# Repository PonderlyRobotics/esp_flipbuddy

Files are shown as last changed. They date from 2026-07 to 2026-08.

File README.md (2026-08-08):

# FlipBuddy







I kept forgetting to start and stop phone time trackers. FlipBuddy is my fix: a printed cube on the desk. Face up means that activity is on (not a countdown alarm). Flip when you switch; stop face when you are done. The cube logs face changes. LEDs show the colors you set in the free app at [flipbuddy.app](https://flipbuddy.app) if you use it.

I thought it would take a weekend. It took months. That is fine. Still a simple cube: flip a face, log the time, check history later in the free app if you want.

Hackaday wrote about the project:  
https://hackaday.com/2026/08/07/flipbuddy-is-borg-you-will-be-assimilated/

This repository is the open DIY build. Firmware is **0.1.4**. It runs on a stock ESP32-S3 (Super Mini class works well) with MicroPython. The shell STLs and assembly PDF are here too. I publish it under **Ponderly Robotics** and work on it when evenings allow, so please treat it as a hobby project, not a product with phone support.

<p align="center">
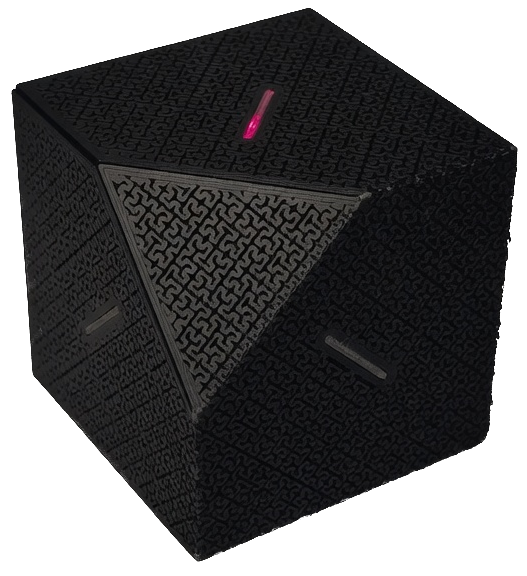
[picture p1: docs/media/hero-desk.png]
FlipBuddy cube with activity LED lit
  
</p>

If you only want to build one, start with the [assembly PDF](./FlipBuddy%20Assembly%20guide.pdf), the files in [stl/](./stl/), the firmware `.bin` from GitHub Releases, then `main.py` and your `credentials.json`. You can ignore `scripts/`, pre-commit, and the rest of the host tooling. People changing the code should read [CONTRIBUTING.md](./CONTRIBUTING.md).

| | |
|--|--|
| Firmware image | `esp32_s3_flipbuddy_0.1.4.bin` on GitHub Releases (MicroPython 1.27; helpers frozen in; not in git) |
| Enclosure | [stl/](./stl/) |
| Assembly | [FlipBuddy Assembly guide.pdf](./FlipBuddy%20Assembly%20guide.pdf) |
| Software license | [MIT](./LICENSE) |
| Hardware license | [CC BY-NC-SA 4.0](./LICENSE-HARDWARE) |

The design is for minutes and hours, not a stopwatch. It prefers boards you can buy today. Other custom modules are not in this tree yet.

## Contents

- [Features in short](#features-in-short)
- [Day to day](#day-to-day)
- [SoftAP maintenance mode](#softap-maintenance-mode)
- [Battery (rough)](#battery-rough)
- [Getting started](#getting-started)
  - [Serial port and board](#serial-port-and-board-justfile)
  - [Fast track (v0.1.4)](#fast-track-v013)
  - [DIY path](#diy-path)
- [Assembly, printing, and parts](#assembly-printing-and-parts)
- [Web app](#web-app)
- [FAQ](#faq)
- [Bugs](#bugs)
- [Contributing](#contributing)
- [License](#license)
- [Links](#links)

## Features in short

- Up to 8 faces (one can be stop)
- Snap-fit printed shell
- RGB LEDs for activity colors from the app
- Deep sleep and longer sleeps on the stop face
- Free web app for names, colors, history, optional AI
- More than one cube per account (stop one in the app before using another a lot)

## Day to day

You set activity names, descriptions, and colors in the browser, plus device settings (for example OTA on/off, how often the cube wakes, and how often it should join Wi-Fi and check in with the server). The cube records which face is up and when (activity periods).

When the cube is online it talks both ways with the free app:
- **Up:** upload face changes (activity periods) for history on flipbuddy.app
- **Down:** pull activity name, description, color, and device configuration for that cube

Wi-Fi is used for those check-ins, sometimes on the stop face, and when USB is plugged in. On stop, sleep intervals grow so the battery lasts longer.

If Wi-Fi is down but credentials are already installed, the cube still boots and can log with defaults (last known face map). Full face colors, fresh names, and history still need flipbuddy.app for normal use.

USB-C face up can open **SoftAP maintenance mode** (local captive portal — see below). Blinking all leds red often means bad orientation or low battery. AI in the app can be turned off.

## SoftAP maintenance mode

When the **USB‑C face** is up (the face with the USB‑C **port**; SoftAP is **on by default** in firmware, advanced builds can disable it), the cube soft‑resets into a short **SoftAP** session so you can check status and fix Wi‑Fi **without** `mpremote`.

Full SoftAP needs the portal modules on the device: the **0.1.4** frozen Release image (or later), **or** DIY/`just diy` (full source upload). Fast track only pushes `main.py` + credentials on top of the frozen set. Risks (open AP, cleartext HTTP, PIN): [SECURITY.md](./SECURITY.md).

| | |
|--|--|
| Join Wi‑Fi | Open network **`FlipBuddy`** (no AP password) |
| Portal URL | [http://10.20.30.40/](http://10.20.30.40/) (captive portal usually opens this) |
| Session length | About **5 minutes**, then SoftAP stops and the cube deep‑sleeps |
| Transport | **HTTP only** (cleartext) |

### Builder steps

1. Put the **USB‑C port face** up. Wait until the phone sees open Wi‑Fi **`FlipBuddy`** (shake to wake if the cube slept).
2. Join **`FlipBuddy`**. If no captive browser popup, open **http://10.20.30.40/**.
3. Unlock with the **setup PIN** (below) if you need to change Wi‑Fi or PIN.
4. Save home SSID/password if needed. Keep **only one phone** on `FlipBuddy` while settings are unlocked ([why](./SECURITY.md#softap-captive-portal-http-pin-wi-fi)).
5. **Exit:**
   - Tap **Reset device** on the portal (preferred after clock issues), **or** wait for SoftAP to end (~5 min).
   - Flip to a **non‑cutout** face (activity or stop — not either shell cutout).
   - On the phone, leave `FlipBuddy` and rejoin your **home** Wi‑Fi.
6. SoftAP again later: **leave the USB face first** (cooldown after a session), then put USB face up again.

**Timeout vs Reset:** SoftAP timeout turns SoftAP off, deepsleeps briefly, then normal wake (may use home Wi‑Fi / NTP if already configured). **Reset device** (or power‑cycle) runs a full boot with forced Wi‑Fi + NTP — use that when the clock is wrong.

### Default unlock PIN

Settings that **write** to the cube need a **setup PIN** unlock for that SoftAP session:

- **Factory default:** last **6** alphanumeric characters of your **`device_id`**, uppercased (ignore hyphens/punctuation).  
  Example: `device_id` ending in `…ABCDEF123456` → default PIN **`123456`**.
- **Custom PIN:** after unlock, set 4–16 letters/numbers on the portal (stored in NVS); then the factory rule no longer applies.
- Wrong PIN is rate‑limited (**8** tries); then unlock locks until reboot. Portal **Reset device** still works and reboots the cube.
- Unlock idles out after about 5 minutes of no settings use — use **Lock settings** when finished.

You can find `device_id` in the downloaded `credentials.json` or in the flipbuddy.app device page. The cube does not display the PIN.

### What the captive portal shows

**Always available (no PIN):**

- Device **UTC time** and **battery** (percent / voltage; USB‑aware) on the top bar
- Face map / activity colors as stored on the cube
- Local activity records not yet uploaded (when any)
- **Reset device** (not PIN‑protected — physical USB‑face access is assumed)

**After PIN unlock:**

- Add or update **Wi‑Fi** profiles (SSID, password, hidden flag) in NVS
- **Change unlock PIN**
- **LED self‑test**
- **Lock** the settings section again

`device_token` is never shown or edited on SoftAP. To replace API credentials, re‑upload `credentials.json` over USB (`just put-credentials` / `just fast-track`).

### Which face is which?

If you have looked at photos or printed one already, you may think: this thing is symmetric, so which side is front, left, or “programming”?

I could have put a different emblem, number, texture, or color on each face. I actually tried. My OCD did not approve of any of them.

So it works like this: when you grab, move, or tap the cube, the accelerometer wakes it and every face that has an activity lights up in that activity’s color. The lights stay on for a few seconds (about 5–7) and dim so you can see the map. I do not need to know if “Human Programming” is assigned to left or bottom. I only need it flashing green and pointing up. Orange is “AI shenanigans” for me. Whichever physical face that is does not matter. Color on top is enough.

## Battery (rough)

With a ~550 mAh LiPo, order-of-magnitude only:

| Scenario | Avg current | Est. life |
|---|---|---|
| Continuous tracking | ~7.4 mA | ~3 days |
| Long stop-face (backoff ~15 min) | ~0.8 mA | ~28 days |
| Mixed use (~10 h tracking/day) | ~3.5 mA | ~6.5 days |

See comments in `main.py` (`prepare_for_deep_sleep`) and `fsm.dot` for the assumptions.

## Getting started

Build and wire the cube first ([assembly section](#assembly-printing--bom) and the [PDF](./FlipBuddy%20Assembly%20guide.pdf)). Pins live in `main.py` / `mpu6050.py`.

| Path | Use when | What you put on the device |
|---|---|---|
| [Fast track](#fast-track-v013) | ESP32-S3 Super Mini (or similar) with charger | Release `.bin`, then `main.py` + `credentials.json` |
| [DIY path](#diy-path) | Other boards, or you want every `.py` on the filesystem | Stock MicroPython + all sources + credentials |

### Serial port and board (`justfile`)

Defaults target an ESP32-S3 Super Mini (4 MB flash) on Linux. Edit the top of [justfile](./justfile) or set `AMPY_PORT`:

```just
usb_dev := env("AMPY_PORT", "/dev/ttyACM0")
esp_chip := "s3"
esp_flash_size := "4MB"
```

| Setting | Default | Notes |
|---|---|---|
| `usb_dev` / `AMPY_PORT` | `/dev/ttyACM0` | Also try `/dev/ttyUSB0`, `COM3`, `/dev/cu.usbmodem*` |
| `esp_chip` | `s3` | Becomes `esp32s3` for esptool |
| `esp_flash_size` | `4MB` | Match your module when picking MicroPython builds |

```bash
just env
```

The Release fast-track image is ESP32-S3 only. Other chips need the DIY path. Commands below use `/dev/ttyACM0` and `esp32s3`; change them if you are not using `just`.

### Fast track (v0.1.4)

Helpers (including SoftAP portal modules) are frozen into the image. You only place `main.py` and `credentials.json` on the filesystem so you can tweak the entrypoint without rebuilding MicroPython.

| | |
|--|--|
| Image | `esp32_s3_flipbuddy_0.1.4.bin` from GitHub **Releases** |
| Checksum | Matching `.bin.sha256` or `SHA256SUMS` on the same release |
| Runtime | MicroPython 1.27 |
| Board | ESP32-S3 Super Mini class with battery charger |

#### 1. Download, verify, flash

Use this README for flashing. The assembly PDF is for mechanics; if it only mentions stock MicroPython, prefer the frozen Release image for Super Mini.

On GitHub: **Releases** → tag **v0.1.4** (or latest 0.1.x). Download the `.bin` and checksum file.

```bash
sha256sum -c esp32_s3_flipbuddy_0.1.4.bin.sha256

esptool --chip esp32s3 --port /dev/ttyACM0 erase-flash
esptool --chip esp32s3 --port /dev/ttyACM0 --baud 460800 write-flash 0 esp32_s3_flipbuddy_0.1.4.bin
```

Or, with the file in the repo directory:

```bash
just flash-firmware esp32_s3_flipbuddy_0.1.4.bin
```

#### 2. Credentials

1. Create a free account at [flipbuddy.app](https://flipbuddy.app)
2. Register a device and download `credentials.json`
3. Add your Wi-Fi (people often skip this):

```json
{
  "device_id": "...",
  "device_token": "...",
  "api_url": "https://api.flipbuddy.app/v1/api/",
  "wifi": {
    "home": { "ssid": "YourWiFi", "password": "secret" }
  }
}
```

The firmware scans for visible SSIDs before connecting. For a hidden network, set `"hidden": true` on that entry.

#### 3. Upload `main.py` and credentials

Put `credentials.json` next to the `justfile`, then:

```bash
just fast-track
# same as: just put-main && just put-credentials
```

That only pushes **`main.py`** and **`credentials.json`**. Do not run `just diy` / `just upload` on the fast track unless you mean to override frozen modules.

Manual equivalent (if you do not use `just`):

```bash
mpremote connect /dev/ttyACM0 cp main.py :
mpremote connect /dev/ttyACM0 cp credentials.json :
```

#### 4. Power cycle

On first boot it will try Wi-Fi, calibrate, fetch face config, then track flips. LEDs should match dashboard colors. Use `just shell` or any 115200 serial console if something looks wrong. Shake the cube if it went to sleep.

### DIY path

For other boards, stock MicroPython, or editing modules on the filesystem.

Get a MicroPython build for your chip and flash size from [micropython.org](https://micropython.org/download/) (1.27+ is a good match). Adjust `justfile` chip/port/flash size as needed.

```bash
esptool --chip esp32s3 --port /dev/ttyACM0 erase-flash
esptool --chip esp32s3 --port /dev/ttyACM0 --baud 460800 write-flash 0 ESP32_GENERIC_S3-....bin
# or: just flash-firmware ESP32_GENERIC_S3-....bin
```

Credentials: same as fast track step 2 (`credentials.json` next to the `justfile`).

```bash
just diy
# same as: just upload && just put-credentials
```

That pushes the firmware modules listed in `device_py` plus credentials. Then power cycle.

## Assembly, printing, and parts

### Guide

- [FlipBuddy Assembly guide.pdf](./FlipBuddy%20Assembly%20guide.pdf): BOM, print list, photos, fold order
- Flash steps: this README (fast track above)

The PDF **Bill of Materials** and **Parts to Print** sections are the shopping and print lists. Tables below are a short summary plus the firmware pin map.

### Photos

| File | Content |
|---|---|
| [docs/media/hero-desk.png](./docs/media/hero-desk.png) | Finished cube |
| [docs/media/print-plate.png](./docs/media/print-plate.png) | Net in the slicer |
| [docs/media/wiring-schematic.png](./docs/media/wiring-schematic.png) | Board, MPU, LEDs, battery |
| [docs/media/dashboard.png](./docs/media/dashboard.png) | Web app |

<p align="center">
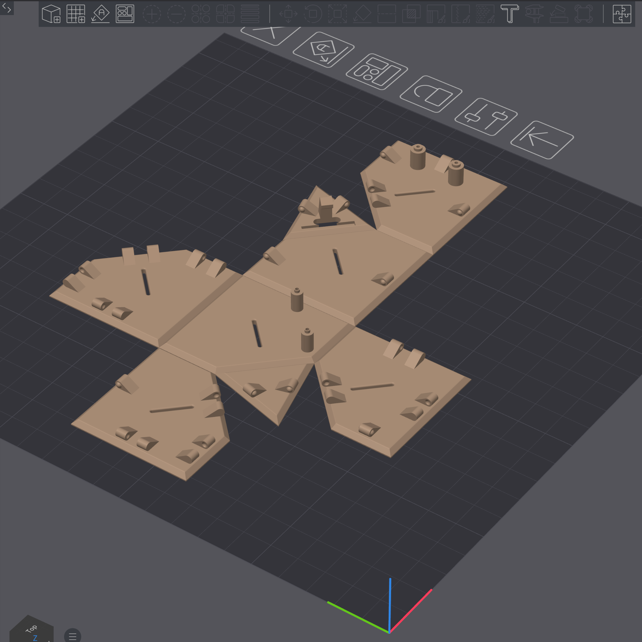
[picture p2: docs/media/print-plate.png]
Cube net on the print plate
  
</p>

### STLs (`stl/`)

Shell parts for the Super Mini pinout below (filenames include a design revision tag):

| File | Role |
|---|---|
| `tolerance_20_…_net.stl` … `tolerance_40_…_net.stl` | Shell nets (tighter → looser fit) |
| `flipbuddy_con_v0.1.0_led_clip.stl` | LED clip |
| `flipbuddy_con_v0.1.0_led_light_guide.stl` | Light guide |
| `flipbuddy_con_v0.1.0_new_mpu6050_clip.stl` | Sensor clip |
| `tolerance_check.stl` | Print first to choose a net |
| `flipbuddy_con_v0.1.0_new_led.FCStd` | FreeCAD (LED-related) |

Print the tolerance check, pick a net, then clips and guides. PLA or PETG at ~0.2 mm layers works for many printers. Follow the PDF for glue points and fold order.

### Pins (Super Mini path)

Use the GPIO numbers on the silkscreen. Super Mini clones are not all identical.

| Function | GPIO |
|---|---|
| NeoPixel VCC gate | 7 |
| NeoPixel data | 8 |
| Battery ADC | 9 |
| MPU INT | 10 |
| I2C SDA | 11 |
| I2C SCL | 12 |
| Onboard LED (if used) | 48 |

LED index order in `rgb.py` (DIN starts at 0): front, bottom, back, left, top, right.

Mount the MPU as in the PDF photos; wrong orientation means wrong faces with “working” firmware.

Worth a quick breadboard test before final soldering: flash, credentials, one LED on 7/8, MPU on 10–12, serial at 115200, shake to wake.

<p align="center">
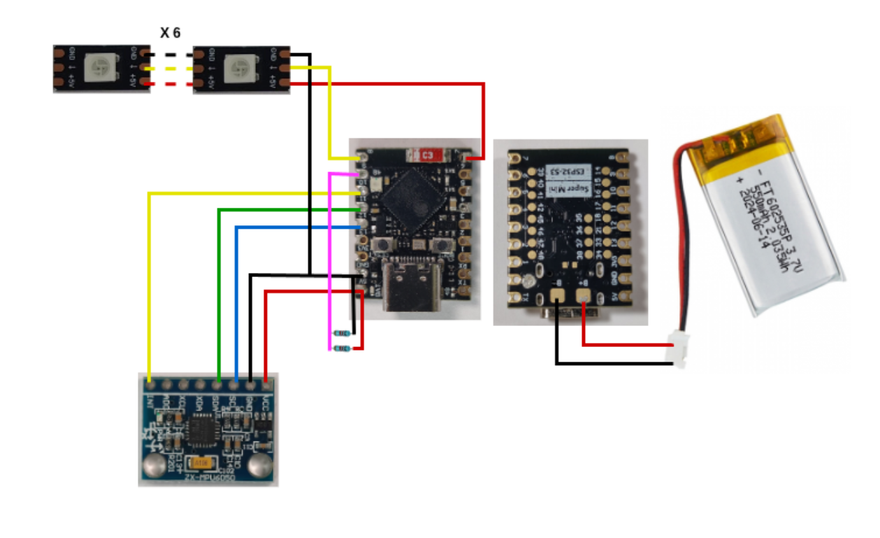
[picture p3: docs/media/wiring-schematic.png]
Wiring schematic
  
</p>

### Parts (summary)

Full list with notes: assembly PDF → **Bill of Materials**.

| Function | Spec | Qty |
|---|---|----:|
| MCU | ESP32-S3 Supermini, USB-C, onboard charger preferred | 1 |
| IMU | MPU6050 / GY-521 | 1 |
| Battery | 3.7 V protected LiPo ~550 mAh | 1 |
| LEDs | WS2812B 5050 | 6 |
| Optional ADC divider | 470 kΩ | 2 |

Print: one net, six guides, six LED clips, one MPU clip (STLs in `stl/`).

Buy a Super Mini-class board that fits the shell cutout and shows GPIO labels for 7–12. Shop links go stale quickly, so the PDF does not hard-code store URLs.

Expect intermediate DIY skills (print, solder, flash). A careful first build often takes more than one evening after parts arrive.

**Safety:** LiPo packs need care. Do not short them, use a proper charger, and do not leave charging unattended. This is a hobby project; you build at your own risk.

## Web app

[flipbuddy.app](https://flipbuddy.app): live status, history, goals, optional AI. The UI is built for the phone first. In browsers that support it, you can install it as a progressive web app (add to home screen).

<p align="center">
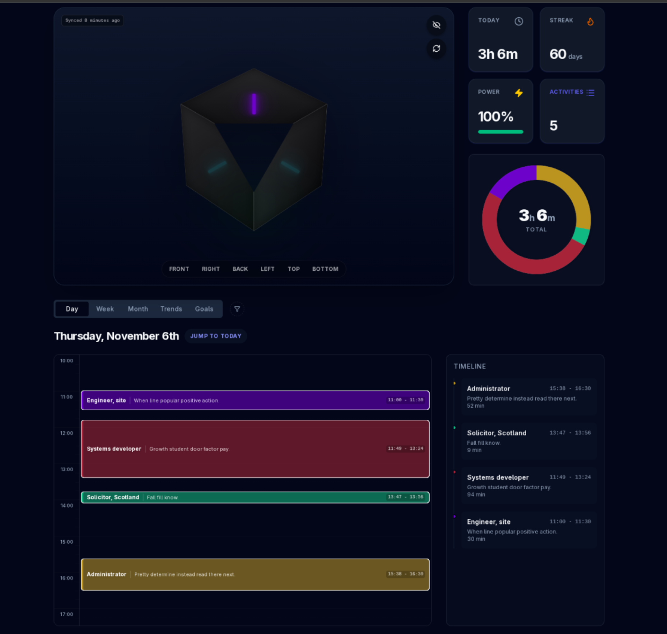
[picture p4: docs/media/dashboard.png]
Web dashboard
  
</p>

Change faces and colors in the browser; the cube picks them up later. For two cubes, stop one in the app before flipping the other a lot. If the cube seems dead, shake it (motion wake). MCP / external AI details are in the dashboard if you use that.

## FAQ

**I haven't charged my FlipBuddy for a long time, and now it does not connect to the dashboard.**  
The device token is valid for up to **60 days** for security (for example if a cube is lost or stolen). Download a **fresh token** from the dashboard into a new `credentials.json`, run `just put-credentials` (or `just fast-track` if you also need to refresh `main.py`), power-cycle, and tracking can continue.

**All six LEDs light cyan / light blue when I shake the cube.**  
No activities are assigned on the device yet. Map faces in the free [dashboard](https://flipbuddy.app), make sure Wi‑Fi works on first sync, then shake again. Until that config is applied, the cube only shows the empty “no faces” indicator.

**I flashed the frozen image but the cube never joins my Wi‑Fi.**  
Confirm `credentials.json` includes a working `wifi` entry (`ssid` / `password`), upload it with `just put-credentials` or `just fast-track`, and that the SSID is visible (the firmware scans before connecting; use `"hidden": true` for non-broadcast networks). After flash, credentials must be re-uploaded — erase/flash clears the filesystem. Check serial with `just shell` (115200) for connect / “no credentials” messages. You can also set or fix Wi‑Fi from the [SoftAP captive portal](#softap-maintenance-mode) after PIN unlock.

**SoftAP / `FlipBuddy` Wi‑Fi does not show up.**  
Shake or wake the cube, put the **USB‑C port face** up, and wait a few seconds. After a SoftAP session, the cube uses a **cooldown** while still on that face — flip to another face, then USB face up again. Confirm SoftAP modules are on the device (DIY/`just diy` or a frozen image that includes the SoftAP stack). Low battery or a failed SoftAP bring‑up falls back to normal boot; serial (`just shell`) shows `ap_session` / SoftAP messages if you have a cable.

**I saved Wi‑Fi on SoftAP but the cube is still offline.**  
On the phone, leave the **`FlipBuddy`** network and rejoin **home** Wi‑Fi. Flip the cube off the USB face (or tap **Reset device**). Confirm the SSID/password and, for hidden networks, the Hidden checkbox. Profile name defaults to `default` on the portal (getting‑started examples often use `home`) — either is fine; the firmware tries configured profiles.

**Recorded times are wrong, or the clock looks fully out of sync.**  
1. Home Wi‑Fi must work first (or fix it via SoftAP). SoftAP top bar cannot prove NTP until the cube has joined home Wi‑Fi on a normal boot.  
2. SoftAP → check the top bar **UTC** time (not your local timezone; the dashboard may show local time).  
3. If **UTC** is wrong and Wi‑Fi works: tap **Reset device**, place the cube on an **activity or stop face (not either cutout)**. Full boot forces **NTP** over home Wi‑Fi. SoftAP **timeout alone** is not the same as that initial boot path.  
4. After a good sync, new sessions get correct timestamps. Old records logged while the RTC was wrong stay wrong — edit them in the [web dashboard](https://flipbuddy.app) if needed.  
5. If UTC looks right but the app “looks wrong,” check timezone/display on the dashboard before assuming the cube clock failed.

## Bugs

Open an issue with what you expected, what happened, board and flash path, serial log if you have one (redact tokens and Wi-Fi passwords). For hardware, photos and which STL/tolerance help.

## Contributing

Builders can stop at the README. Code and tooling: [CONTRIBUTING.md](./CONTRIBUTING.md). Small, focused pull requests are welcome when I have time to review.

## License

| What | License |
|---|---|
| Software (`.py`, host tools, tests) | [MIT](./LICENSE) |
| Hardware / CAD / assembly PDF / `stl/` | [CC BY-NC-SA 4.0](./LICENSE-HARDWARE) |
| Frozen Release `.bin` | FlipBuddy bits MIT; also MicroPython and other third-party code ([docs/NOTICE](./docs/NOTICE)) |

Copyright 2025–2026 Ponderly Robotics.

If you want to use the enclosure designs commercially, please ask first. The non-commercial share-alike terms on the hardware are intentional.

## Links

- App: https://flipbuddy.app
- Hackaday write-up: https://hackaday.com/2026/08/07/flipbuddy-is-borg-you-will-be-assimilated/
- Firmware binaries: GitHub Releases (`esp32_s3_flipbuddy_*.bin` + checksums)
- [Assembly PDF](./FlipBuddy%20Assembly%20guide.pdf)
- [stl/](./stl/)
- [docs/media/](./docs/media/)
- [CONTRIBUTING.md](./CONTRIBUTING.md)
- [SECURITY.md](./SECURITY.md)
- [docs/CHANGELOG.md](./docs/CHANGELOG.md), [docs/NOTICE](./docs/NOTICE), [docs/RELEASE_NOTES_v0.1.4.md](./docs/RELEASE_NOTES_v0.1.4.md)
- [LICENSE](./LICENSE), [LICENSE-HARDWARE](./LICENSE-HARDWARE)

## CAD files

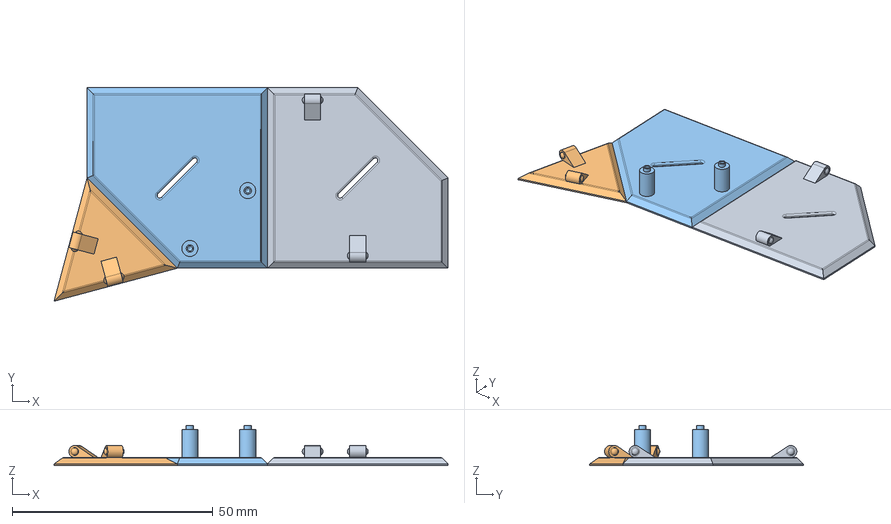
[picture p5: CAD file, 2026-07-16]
stl/flipbuddy_con_v0.1.0_new_led.FCStd
98.2 x 53.2 x 10.0 mm
right
front_cutout
bottom

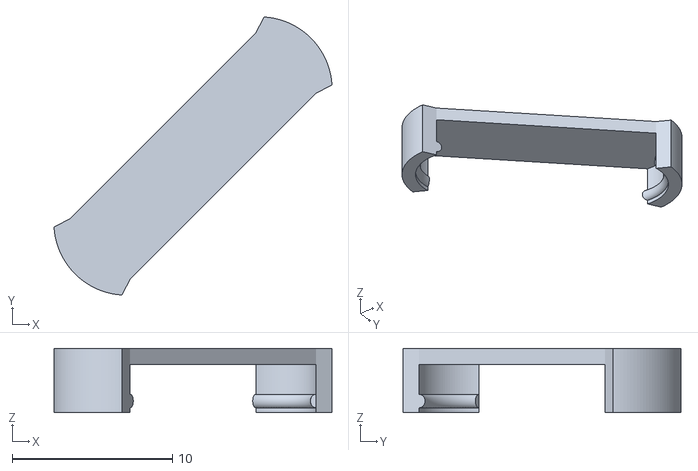
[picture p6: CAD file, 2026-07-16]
stl/flipbuddy_con_v0.1.0_led_clip.stl
17.3 x 17.3 x 4.00

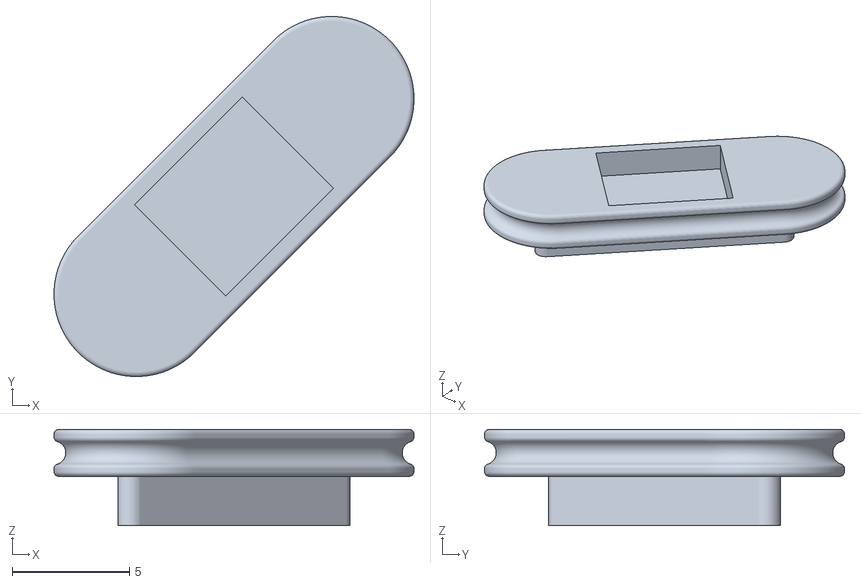
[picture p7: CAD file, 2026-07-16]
stl/flipbuddy_con_v0.1.0_led_light_guide.stl
15.4 x 15.4 x 4.10

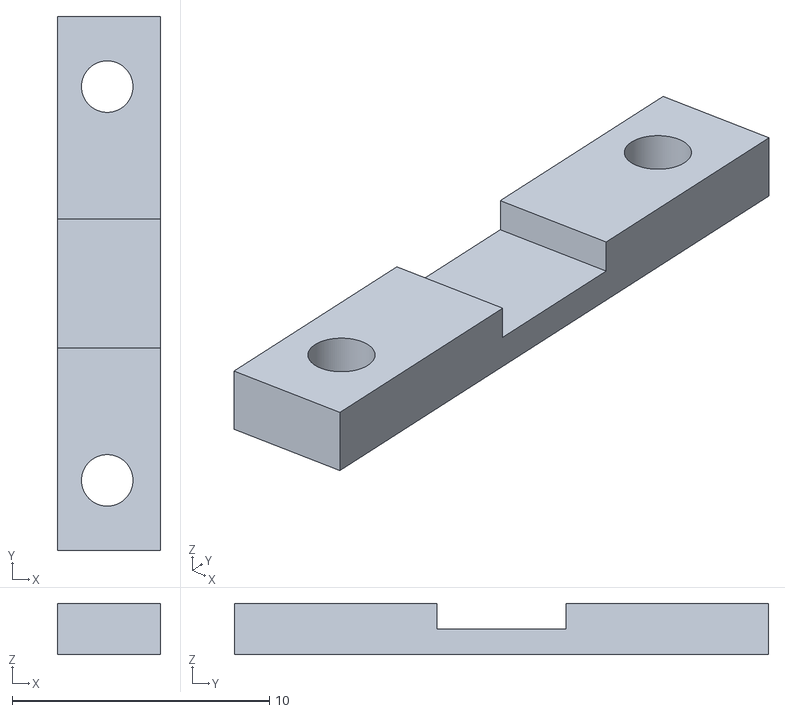
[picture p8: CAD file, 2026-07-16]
stl/flipbuddy_con_v0.1.0_new_mpu6050_clip.stl
4.00 x 20.8 x 2.00

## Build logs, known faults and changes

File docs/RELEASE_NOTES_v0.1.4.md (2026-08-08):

# FlipBuddy v0.1.4

Firmware **0.1.4** is a maintenance release focused on internal optimizations for memory usage and tracking durability. It contains no new user-facing features but significantly improves long-term stability.

## Highlights

- **Memory Optimization:** Reduced initial RAM usage by **~11.6 KB** on startup by converting global defaults to `const()` and using static strings for FSM states. This reduces heap fragmentation and lowers the risk of `OutOfMemoryError` during long-running operation.
- **Improved Session Durability:** Open tracking sessions are now intelligently reconciled after a reboot or power loss. The firmware checks for sessions that were running before a reset and either resumes them or force-closes them into the log, preventing data loss.
- **Better NVS Hygiene:** Ephemeral, single-upload data (e.g., battery voltage) is no longer saved to non-volatile storage. This reduces unnecessary flash writes and prevents the NVS from accumulating temporary data.
- **Documentation:** Added the official Hackaday.io project link and clarified the project's scope in the README.

## Upgrade

This is a recommended firmware update for all users. It includes significant memory and stability optimizations.

### From v0.1.3

1.  Download `esp32_s3_flipbuddy_0.1.4.bin` and its checksum from this Release.
2.  Verify the checksum and perform a **full firmware reflash**, as the optimizations are baked into the frozen modules.

    ```bash
    sha256sum -c esp32_s3_flipbuddy_0.1.4.bin.sha256
    esptool --chip esp32s3 --port /dev/ttyACM0 erase-flash
    esptool --chip esp32s3 --port /dev/ttyACM0 --baud 460800 write-flash 0 esp32_s3_flipbuddy_0.1.4.bin
    ```
3.  After flashing, upload your `credentials.json` and the latest `main.py` again.
4.  Power cycle the device.

### From v0.1.2 or earlier

Same full reflash procedure. This update includes all previous fixes, including the critical pinout and gravity remaps from v0.1.2 and v0.1.3.

## Files on this Release

| File | Purpose |
| --- | --- |
| `esp32_s3_flipbuddy_0.1.4.bin` | Frozen image with MicroPython 1.27 and all firmware optimizations. |
| `esp32_s3_flipbuddy_0.1.4.bin.sha256` | Checksum for the firmware binary. |
| `SHA256SUMS` | Full list of release file digests. |

```bash
sha256sum -c esp32_s3_flipbuddy_0.1.4.bin.sha256
```

Expected digest:
```
a2201ff7b3118e1b1f6fada2c02bb146f70a1771d6189f50b6d74e8615a29c2a  esp32_s3_flipbuddy_0.1.4.bin
```

## Links

- App: https://flipbuddy.app
- Changelog: [CHANGELOG.md](https://github.com/PonderlyRobotics/esp_flipbuddy/blob/main/docs/CHANGELOG.md)
- Prior notes: [v0.1.3](./RELEASE_NOTES_v0.1.3.md), [v0.1.2](./RELEASE_NOTES_v0.1.2.md), [v0.1.1](./RELEASE_NOTES_v0.1.1.md), [v0.1.0](./RELEASE_NOTES_v0.1.0.md)
- This GitHub repository for source, STLs, and docs

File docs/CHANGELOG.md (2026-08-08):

# Changelog

Versions follow `pyproject.toml` and the GitHub Release tags (firmware / source tree).

## 0.1.4 (2026-08-08)

Maintenance release with internal firmware optimizations for memory and stability.

- **Memory Optimization:** Reduced initial RAM usage by ~11.6 KB through `const()` declarations and static FSM state strings, lowering heap fragmentation.
- **Session Durability:** Open tracking sessions are now reconciled after a reboot, preventing data loss.
- **NVS Hygiene:** Ephemeral data is no longer saved to non-volatile storage, reducing flash writes.

Frozen Release image: `esp32_s3_flipbuddy_0.1.4.bin`. Full reflash recommended. See [RELEASE_NOTES_v0.1.4.md](./RELEASE_NOTES_v0.1.4.md).

## 0.1.3 (2026-07-31)

Cutout triad LED fix (prefer this over 0.1.2 for new flashes):

- Swap `triad_led` mappings so after the 0.1.2 pinout rename, `front_cutout` lights bottom/left/back and `back_cutout` lights top/right/front
- Flat-face gravity remap and pinout labels unchanged from 0.1.2

Frozen Release image: `esp32_s3_flipbuddy_0.1.3.bin`. Full reflash required (frozen `rgb.py`). See [RELEASE_NOTES_v0.1.3.md](./RELEASE_NOTES_v0.1.3.md).

## 0.1.2 (2026-07-31)

Face orientation aligned to the physical LED chain and enclosure:

- Remap NeoPixel face labels in `rgb.py` pinout (DIN 0…5): back→front, left→bottom, front→back, bottom→left, right→top, top→right
- Same rename in `cube_face_upward()` gravity returns so upward face, LED, and tracker name agree
- Cutout triad tuples were updated with the rename but **swapped** relative to front/back cutout — fixed in **0.1.3**
- CI: GitHub Actions `checkout` and `setup-python` majors that run on Node 24

Frozen Release image: `esp32_s3_flipbuddy_0.1.2.bin` (known cutout triad bug). Prefer **0.1.3**. See [RELEASE_NOTES_v0.1.2.md](./RELEASE_NOTES_v0.1.2.md).

## 0.1.1 (2026-07-22)

SoftAP maintenance mode and related host tooling:

- SoftAP captive portal on USB‑C face: status (UTC time, battery), PIN unlock, Wi‑Fi profiles, change PIN, LED self‑test, ungated device reset
- Early SoftAP gate + `ap_session` clean‑heap path (soft_reset handoff); lazy STA / SoftAP radio helpers
- Host tests under `tests/` (PIN, Wi‑Fi NVS, portal HTML helpers, handoff marks); CI runs `pytest tests/`
- README SoftAP builder steps, clock/Wi‑Fi FAQs; SECURITY SoftAP risks (cleartext HTTP, multi‑client unlock, factory PIN)
- Factory setup PIN = last 6 alphanumeric of `device_id`; optional custom PIN in NVS

Fast track: flash `esp32_s3_flipbuddy_0.1.1.bin` (when published on GitHub Releases), then place `main.py` + credentials. DIY / `just diy` still works with stock MicroPython + full sources.

## 0.1.0 (2026-07-16)

First public DIY release under Ponderly Robotics.

What is in the box, so to speak:

- MicroPython sources (Boot, Active, and Upload FSMs)
- Assembly PDF and STLs for enclosure v0.1.0
- Photos, wiring schematic, and dashboard screenshot in `docs/media/`
- MIT for software, CC BY-NC-SA 4.0 for hardware; frozen images also carry third-party code (see [NOTICE](./NOTICE))
- [SECURITY.md](../SECURITY.md)
- Fast track: frozen ESP32-S3 image on GitHub Releases (MicroPython 1.27); only `main.py` and `credentials.json` on the filesystem
- DIY path: stock MicroPython plus full source upload
- Continues offline if Wi-Fi is missing once credentials are installed
- Token rotate keeps Wi-Fi settings and updates the headers still in memory
- Host tools: `just`, tests, pre-commit, release-check, CI
- Aimed at ESP32-S3 Super Mini boards with a charger; full BOM is in the assembly PDF

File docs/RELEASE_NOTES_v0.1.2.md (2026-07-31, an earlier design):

# FlipBuddy v0.1.2

Firmware **0.1.2** release: face orientation and NeoPixel pinout aligned to the physical enclosure.

> **Superseded for cutout LEDs:** 0.1.2 had swapped SoftAP / cutout **triad** faces. New flashes should use **[0.1.3](./RELEASE_NOTES_v0.1.3.md)** (`esp32_s3_flipbuddy_0.1.3.bin`). Flat-face remap below is still correct and carried forward.

This is a small but important hardware-alignment fix on top of **0.1.1**. SoftAP maintenance mode, frozen MicroPython 1.27 stack, and the fast-track workflow are unchanged. If the wrong LED lit when you flipped a face, or tracking names did not match the side you held up, reflash this image (or better, 0.1.3).

## Highlights

- **Correct face names for gravity detection** — `cube_face_upward()` returns the same face labels used by the tracker, dashboard, and LEDs
- **NeoPixel pinout renamed** to match the LED chain on the board / enclosure (DIN index 0…5)
- **Cutout triad LEDs updated** so USB / front cutout blink patterns still light the right three cells
- **Cutout orientation names unchanged** — `front_cutout` / `back_cutout` (SoftAP USB face) keep the same roll/pitch detection
- Host CI: checkout + setup-python actions on Node 24 majors (tooling only)

## What changed (face remap)

Physical gravity axes were already stable. What was wrong was the **name** attached to each axis and each LED index. Detection and pinout now use one shared rename:

| Old face name | New face name |
|---|---|
| `back` | `front` |
| `left` | `bottom` |
| `front` | `back` |
| `bottom` | `left` |
| `right` | `top` |
| `top` | `right` |

### LED chain (DIN starts at 0)

| Index | 0.1.1 label | 0.1.2 label |
|---:|---|---|
| 0 | back | **front** |
| 1 | left | **bottom**  |
| 2 | front | **back** |
| 3 | bottom | **left** |
| 4 | right | **top** |
| 5 | top | **right** |

### Gravity → name (`cube_face_upward`)

| Dominant axis | 0.1.1 return | 0.1.2 return |
|---|---|---|
| +Z / −Z | bottom / top | **left** / **right** |
| +X / −X | left / right | **bottom** / **top** |
| +Y / −Y | back / front | **front** / **back** |

Modules touched in source: `rgb.py` (pinout + triad), `mpu6050.py` (`cube_face_upward` only). Both ship **frozen** in the Release `.bin`, so this fix is not applied by uploading `main.py` alone.

## Why upgrade

- Upward face, lit LED, and dashboard face name should agree after assembly
- Activity colors map to the physical side you intend when assigning faces in the app / SoftAP status view
- DIY builders who already flashed 0.1.1 with a finished cube get correct orientation without rewiring LEDs

If you never noticed swapped faces, you can stay on 0.1.1; behavior is otherwise the same SoftAP + tracking stack.

## Upgrade from 0.1.1

1. Download **`esp32_s3_flipbuddy_0.1.2.bin`** and its `.sha256` from this Release.
2. Verify checksum (below).
3. **Reflash the full frozen image** (erase optional but recommended if you had a messy filesystem):

   ```bash
   sha256sum -c esp32_s3_flipbuddy_0.1.2.bin.sha256
   esptool --chip esp32s3 --port /dev/ttyACM0 erase-flash
   esptool --chip esp32s3 --port /dev/ttyACM0 --baud 460800 write-flash 0 esp32_s3_flipbuddy_0.1.2.bin
   ```

   Or from a checkout that has the file:

   ```bash
   just flash-firmware build/esp32_s3_flipbuddy_0.1.2.bin
   ```

4. Put **`main.py`** and **`credentials.json`** again (fast track). NVS Wi‑Fi / PIN from SoftAP usually survive a flash; if STA fails, re-enter Wi‑Fi via SoftAP or credentials.
5. Power cycle. Flip each face once: the LED on the **up** face should match that face’s activity color.

### Activity map note

Face **names** in the free app / tracker (`front`, `back`, `left`, `right`, `top`, `bottom`) are unchanged as API strings. What moved is which **physical** side of the cube those names refer to after assembly. If you had mentally assigned “this painted side is left” under 0.1.1’s wrong map, re-check assignments after upgrading — the firmware names should now match the enclosure orientation described in the assembly PDF / wiring notes.

SoftAP factory PIN, custom PIN, multi-profile Wi‑Fi, and USB-face portal behavior are the same as 0.1.1. See README SoftAP section and [SECURITY.md](../SECURITY.md).

## Files on this Release

| File | Purpose |
|---|---|
| `esp32_s3_flipbuddy_0.1.2.bin` | Frozen image (MicroPython 1.27 + FlipBuddy modules, face remap applied) |
| `esp32_s3_flipbuddy_0.1.2.bin.sha256` | Checksum |
| `SHA256SUMS` | Same digests (when attached) |

```bash
sha256sum -c esp32_s3_flipbuddy_0.1.2.bin.sha256
```

Expected digest for the published image:

```
5db186d3c28633d95de4b0d9928d799049a65943df50b7509b63e27eda13a593  esp32_s3_flipbuddy_0.1.2.bin
```

## Quick start (Super Mini)

1. Flash the **0.1.2** `.bin` (README fast track).
2. Upload only **`main.py`** and your **`credentials.json`** (Wi‑Fi under `wifi.<name>`).
3. Power cycle. Shake if it already deep-slept.
4. SoftAP: USB‑C face up → join open Wi‑Fi **`FlipBuddy`** → portal `http://10.20.30.40/`.

DIY / `just diy` on stock MicroPython still works: upload full sources (including updated `rgb.py` and `mpu6050.py`) instead of the frozen image.

Full SoftAP steps, PIN rules, clock FAQ: repository README. SoftAP risks: [SECURITY.md](../SECURITY.md).

## What is not in this release

- No new SoftAP features (those landed in 0.1.1)
- No enclosure / STL / assembly PDF revision
- No API or credentials schema change
- No MicroPython version bump (still 1.27)

## License

- Sources: MIT
- Enclosure, CAD, assembly PDF: CC BY-NC-SA 4.0
- The `.bin` also contains MicroPython and other third-party code: see [NOTICE](./NOTICE)

## Links

- App: https://flipbuddy.app
- Changelog: [CHANGELOG.md](./CHANGELOG.md)
- Prior notes: [v0.1.1](./RELEASE_NOTES_v0.1.1.md), [v0.1.0](./RELEASE_NOTES_v0.1.0.md)
- This GitHub repository for source, STLs, and docs

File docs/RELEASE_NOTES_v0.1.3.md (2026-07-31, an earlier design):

# FlipBuddy v0.1.3

Firmware **0.1.3** release: cutout triad LED fix on top of the 0.1.2 face pinout remap.

If you already flashed **0.1.2**, reflash this image. Flat-face tracking was fine on 0.1.2; **USB / front cutout** triad patterns lit the wrong three cells.

## Highlights

- **Correct cutout triad faces** after the 0.1.2 pinout rename:
  - `front_cutout` → `bottom`, `left`, `back`
  - `back_cutout` → `top`, `right`, `front`
- Same face gravity remap and NeoPixel labels as **0.1.2** (no further rename)
- SoftAP, MicroPython 1.27 frozen stack, and fast-track workflow unchanged

## What was wrong in 0.1.2

0.1.2 remapped the six flat faces and also swapped the cutout **triad** tuples with the pinout rename. That put the wrong three LEDs on `front_cutout` / `back_cutout` blink patterns. Detection names (`front_cutout` / `back_cutout`) and roll/pitch thresholds were never the bug — only which NeoPixel indices blinked.

## Cutout LEDs (0.1.3)

| Orientation | Triad faces | DIN indices |
|---|---|---|
| `front_cutout` | bottom, left, back | 1, 3, 2 |
| `back_cutout`  | top, right, front | 4, 5, 0 |

(Plus each cutout’s own `led_pin` during the blink loop: front_cutout → bottom; back_cutout → top.)

## Flat faces (unchanged from 0.1.2)

| Old name | New name |
|---|---|
| back | front |
| left | bottom |
| front | back |
| bottom | left |
| right | top |
| top | right |

LED DIN 0…5: **front, bottom, back, left, top, right**.

## Upgrade

### From 0.1.2

1. Download `esp32_s3_flipbuddy_0.1.3.bin` + checksum from this Release.
2. Verify and **full reflash** (frozen modules include `rgb.py`):

   ```bash
   sha256sum -c esp32_s3_flipbuddy_0.1.3.bin.sha256
   esptool --chip esp32s3 --port /dev/ttyACM0 erase-flash
   esptool --chip esp32s3 --port /dev/ttyACM0 --baud 460800 write-flash 0 esp32_s3_flipbuddy_0.1.3.bin
   ```

   Or: `just flash-firmware build/esp32_s3_flipbuddy_0.1.3.bin`

3. Put `main.py` + `credentials.json` again. Power cycle.
4. Rest USB face (`back_cutout`) and the opposite cutout once — triad colors should match the three faces around that corner.

### From 0.1.1 or earlier

Same full reflash; you also get the 0.1.2 face pinout / gravity fix. See [RELEASE_NOTES_v0.1.2.md](./RELEASE_NOTES_v0.1.2.md).

## Files on this Release

| File | Purpose |
|---|---|
| `esp32_s3_flipbuddy_0.1.3.bin` | Frozen image (MicroPython 1.27 + SoftAP + face remap + triad fix) |
| `esp32_s3_flipbuddy_0.1.3.bin.sha256` | Checksum |
| `SHA256SUMS` | Digests (when attached) |

```bash
sha256sum -c esp32_s3_flipbuddy_0.1.3.bin.sha256
```

Expected digest:

```
53e11655c321b035f680131f0a4b84af39bae2ef0512c5996fe7665e292c4131  esp32_s3_flipbuddy_0.1.3.bin
```

## Quick start (Super Mini)

1. Flash the **0.1.3** `.bin` (README fast track).
2. Upload only **`main.py`** and **`credentials.json`**.
3. Power cycle. SoftAP: USB‑C face up → Wi‑Fi **`FlipBuddy`** → `http://10.20.30.40/`.

DIY / `just diy`: upload full sources including the fixed `rgb.py`.

SoftAP risks: [SECURITY.md](../SECURITY.md).

## What is not in this release

- No new SoftAP features
- No enclosure / STL changes
- No MicroPython version bump (still 1.27)
- Tag **v0.1.2** is left as published (known triad bug); use **0.1.3** for new flashes

## License

- Sources: MIT
- Enclosure, CAD, assembly PDF: CC BY-NC-SA 4.0
- The `.bin` also contains MicroPython and other third-party code: see [NOTICE](./NOTICE)

## Links

- App: https://flipbuddy.app
- Changelog: [CHANGELOG.md](./CHANGELOG.md)
- Prior notes: [v0.1.2](./RELEASE_NOTES_v0.1.2.md), [v0.1.1](./RELEASE_NOTES_v0.1.1.md), [v0.1.0](./RELEASE_NOTES_v0.1.0.md)
- This GitHub repository for source, STLs, and docs

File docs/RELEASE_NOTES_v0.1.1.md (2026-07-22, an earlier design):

# FlipBuddy v0.1.1

Firmware **0.1.1** release: SoftAP maintenance mode and related host tooling.

## Highlights

- **SoftAP maintenance mode** on the USB‑C face: join open Wi‑Fi **`FlipBuddy`**, portal at `http://10.20.30.40/`
- Status without PIN: **UTC time**, battery, faces, local activity records, **Reset device**
- After setup PIN: Wi‑Fi profiles, change PIN, LED self‑test
- Factory PIN = last 6 alphanumeric of `device_id` (or custom PIN in NVS)
- Clean-heap SoftAP path (`ap_session` + early gate); lazy STA helpers
- Host tests + CI for SoftAP helpers; docs in README and SECURITY

## Files on this Release

| File | Purpose |
|---|---|
| `esp32_s3_flipbuddy_0.1.1.bin` | Frozen image (MicroPython 1.27 + FlipBuddy modules including SoftAP stack) |
| `esp32_s3_flipbuddy_0.1.1.bin.sha256` | Checksum |
| `SHA256SUMS` | Same digests |

```bash
sha256sum -c esp32_s3_flipbuddy_0.1.1.bin.sha256
```

## Quick start (Super Mini)

1. Flash the **0.1.1** `.bin` (README fast track).
2. Upload only **`main.py`** and your **`credentials.json`**.
3. Power cycle. SoftAP: USB‑C face up → `FlipBuddy` → portal.

Full SoftAP steps, PIN rules, and clock FAQ: repository README. SoftAP risks: SECURITY.md.

## License

- Sources: MIT
- Enclosure, CAD, assembly PDF: CC BY-NC-SA 4.0
- The `.bin` also contains MicroPython and other third-party code: see [NOTICE](./NOTICE)

## Links

- https://flipbuddy.app
- This GitHub repository for source, STLs, and docs

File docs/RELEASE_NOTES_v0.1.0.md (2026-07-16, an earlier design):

# FlipBuddy v0.1.0

This is the first public DIY release under Ponderly Robotics.

You get a printed 8-face cube and MicroPython firmware for a stock ESP32-S3. Sessions show up in the free app at [flipbuddy.app](https://flipbuddy.app). I built it because I kept forgetting phone timers; I maintain it when I have free evenings.

## Who it is for

If you already print parts, can solder a little, and have flashed an ESP board before, you are in the right place. This is not a sealed consumer kit.

## Files on this Release

| File | Purpose |
|---|---|
| `esp32_s3_flipbuddy_0.1.0.bin` | Frozen image (MicroPython 1.27 + FlipBuddy modules) |
| `esp32_s3_flipbuddy_0.1.0.bin.sha256` | Checksum |
| `SHA256SUMS` | Same digests |

```bash
sha256sum -c esp32_s3_flipbuddy_0.1.0.bin.sha256
```

## Quick start (Super Mini)

1. Print from `stl/` (the assembly PDF and `tolerance_check.stl` help).
2. Flash the `.bin` (details in the README).
3. Upload only `main.py` and your `credentials.json` (put Wi-Fi in the JSON).
4. Power cycle. Shake the cube if it already went to sleep.

The full walkthrough is in the repository README.

## License

- Sources: MIT
- Enclosure, CAD, assembly PDF: CC BY-NC-SA 4.0
- The `.bin` also contains MicroPython and other third-party code: see [NOTICE](./NOTICE)

## Links

- https://flipbuddy.app
- This GitHub repository for source, STLs, and docs

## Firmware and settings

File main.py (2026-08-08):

# SoftAP early gate — MUST stay before heavy imports.
# After machine.soft_reset() the heap is clean; we bring SoftAP up here (no boot.py).
# RTC marks: FBAP1 = run SoftAP on this boot; APDON = already tried this USB face.
_AP_BOOT_MARK = b"FBAP1"
_AP_DONE_MARK = b"APDON"
SOFTAP_CAPTIVE_PORTAL_ENABLED = True


def _early_softap_gate():
    """If ActiveFSM requested SoftAP via soft_reset, run portal before loading main stack."""
    try:
        from machine import RTC, reset_cause
    except Exception:
        return
    try:
        from machine import SOFT_RESET
    except ImportError:
        SOFT_RESET = 5  # MicroPython ESP32
    try:
        rtc = RTC()
        mem = rtc.memory()
    except Exception:
        return
    if not mem or len(mem) < 5 or mem[:5] != _AP_BOOT_MARK:
        return
    # Stale FBAP1 after power-on/hard reset must not steal BootFSM (WiFi/NTP/config).
    try:
        cause = reset_cause()
    except Exception:
        cause = -1
    if cause != SOFT_RESET:
        try:
            rtc.memory(b"")
        except Exception:
            pass
        return
    try:
        rtc.memory(_AP_DONE_MARK)
    except Exception:
        pass
    try:
        gc.collect()
        import ap_session

        # Success: portal then deepsleep (does not return).
        # Failure: returns so heavy imports + BootFSM/ActiveFSM still run.
        ap_session.run()
        gc.collect()
    except Exception as e:
        try:
            print("early SoftAP gate:", e)
        except Exception:
            pass


_early_softap_gate()

# --- normal firmware (heavy imports only after SoftAP gate) ---
# E402 ignored for this file in pyproject.toml (gate before models/MPU/http).
import gc
from http import (
    async_post_request,
    async_rotate_device_token,
    get_request,
)

import esp32
import mip
import neopixel
import uasyncio as asyncio
import utime as time
from credentials import load_credentials
from machine import (
    ADC,
    DEEPSLEEP_RESET,
    PIN_WAKE,
    RTC,
    Pin,
    Timer,
    deepsleep,
    freq,
    reset,
    reset_cause,
    wake_reason,
)
from micropython import const
from models import BaseFSM, Config, Tracker, Transition, to_serializable
from mpu6050 import cube_face_upward, sensor_init
from network_helper import (
    async_do_connect,
    release_sta,
    release_wifi_radios,
    stop_softap,
)
import network_helper
from ntptime import settime as ntp_settime
from util import read_battery_voltage, rgb_self_test, str_to_epoch, suppress, time_iso

# 240Mhz Note: Going lower cause led flicker due to software based async execution
freq(240000000)

DEFAULT_BAT_CAPACITY = const(550)
DEFAULT_SLEEP_TIME = const(18)  # seconds
DEFAULT_UPLOAD_FRQ = const(300)  # seconds
DEFAULT_OTA = const(7)  # days
DEFAULT_INDICATOR_BLINK_DURATION = const(7000)  # ms
DEFAULT_INDICATOR_BLINK_CYCLE = const(1)
MAX_SLEEP_TIME = const(900)  # seconds
FACES = const(("front", "back", "left", "right", "top", "bottom"))

# Hardware pins
NP_VCC_PIN = const(7)
NP_DATA_PIN = const(8)
VIN_PIN = const(9)
ONBOARD_LED = const(48)

# NeoPixel
NUM_LEDS = const(6)
SDA_PIN = const(11)
SCL_PIN = const(12)
INTERRUPT_PIN = const(10)

# Battery ADC settings
BATTERY_FULL_V = const(4.2)
BATTERY_CUTOFF_V = const(2.8)
BATTERY_NOMINAL_V = const(3.7)

USB_VOLTAGE_THRESHOLD = const(4.3)  # > this → USB power

# General
TIMER_NUM = const(1)
# PIN_WAKE = 7  # micropython passed gpio wake reason directly when GPIO is used for wake not ext0/1

DEBUG = False


def dprint(*args, **kwargs):
    """Debug print that can be disabled. All other prints in main.py were converted to this."""
    if DEBUG:
        print(*args, **kwargs)


# ----------------------------------
# -- Global objects & credentials --
# ----------------------------------
np_obj = neopixel.NeoPixel(Pin(NP_DATA_PIN), NUM_LEDS)

device_cred = load_credentials()
# Do NOT raise SystemExit here — on MicroPython that soft-reboots and loops.
# Fall through to a clean end of main.py so the friendly REPL stays up for upload.
CREDENTIALS_OK = bool(
    device_cred and device_cred.get("device_id") and device_cred.get("device_token")
)
if not CREDENTIALS_OK:
    print("=" * 48)
    print("FATAL: no device credentials (device_id / device_token).")
    print("  1. Download credentials.json from flipbuddy.app")
    print('  2. Add Wi-Fi under wifi.<name>: {"ssid": "...", "password": "..."}')
    print('     Example: "wifi": {"home": {"ssid": "MyNet", "password": "secret"}}')
    print('     Hidden SSID: set "hidden": true on that entry')
    print("  3. just put-credentials   (or just fast-track)")
    print("  4. Power cycle (or soft-reboot)")
    print("=" * 48)
    print("Staying at REPL - app not started.")
    TOKEN = ""
    HEADERS = {}
    API_BASE = "https://api.flipbuddy.app/v1/api/"
else:
    TOKEN = device_cred["device_id"]
    HEADERS = {
        "Device-ID": device_cred["device_id"],
        "Device-Token": device_cred["device_token"],
        "User-Agent": "Mozilla/5.0 (compatible; FlipBuddy/ESP32; +https://flipbuddy.app)",
        "Accept": "application/json, text/plain, */*",
        "Accept-Language": "en-US,en;q=0.5",
        "Connection": "close",
    }
    API_BASE = device_cred.get("api_url", "https://api.flipbuddy.app/v1/api/")
    if not API_BASE.endswith("/"):
        API_BASE += "/"

rtc_mem = RTC()


async def get_remote_config():
    """Fetch remote configuration from the server."""
    try:
        return await get_request(
            API_BASE + f"sensor/data/{TOKEN}/", extra_header=HEADERS
        )
    except Exception:
        return False


async def push_tracking_log_to_remote(data, timeout=5):
    """Push tracking log data to the remote server asynchronously and return success status."""
    dprint("API_BASE:", API_BASE)
    try:
        # Rotate may issue a new token (saved to NVS). Also refresh in-memory
        # HEADERS so this same wake's POST does not still send the old token.
        new_token = await async_rotate_device_token(API_BASE + "sensor/token/rotate/")
        if new_token:
            HEADERS["Device-Token"] = new_token
        return (
            await async_post_request(
                API_BASE + "sensor/data/", data, extra_header=HEADERS, timeout=timeout
            )
            is not None
        )
    except Exception:
        return False


def retrieve_last_backoff(default_sleep_time):
    """Retrieve the last backoff state from RTC memory."""
    backoff_state = rtc_mem.memory()
    if backoff_state:
        # Ignore AP markers and other non-backoff payloads
        prefix = backoff_state[:5]
        if prefix in (_AP_BOOT_MARK, _AP_DONE_MARK):
            return 0, default_sleep_time
        try:
            backoff_counter, prev_sleep_time = map(
                int, backoff_state.decode().split(",")
            )
        except ValueError:
            backoff_counter, prev_sleep_time = 0, default_sleep_time
    else:
        backoff_counter, prev_sleep_time = 0, default_sleep_time
    return backoff_counter, prev_sleep_time


def is_ap_cooldown():
    """True if we already attempted AP for this USB-face placement."""
    try:
        mem = rtc_mem.memory()
        return bool(mem and mem[:5] == _AP_DONE_MARK)
    except Exception:
        return False


def set_ap_cooldown():
    """Block another AP clean-reboot until USB face is left."""
    try:
        rtc_mem.memory(_AP_DONE_MARK)
    except Exception:
        pass


def clear_ap_cooldown():
    """Allow AP again after leaving back_cutout."""
    try:
        mem = rtc_mem.memory()
        if mem and mem[:5] in (_AP_DONE_MARK, _AP_BOOT_MARK):
            reset_backoff(DEFAULT_SLEEP_TIME)
    except Exception:
        pass


def request_ap_soft_reset_handoff():
    """Soft-reset into early SoftAP gate (clean heap). Does not return on success."""
    rtc_mem.memory(_AP_BOOT_MARK)
    dprint("AP mode: soft_reset -> early SoftAP gate...")

    global scheduler_wd
    try:
        if "scheduler_wd" in globals() and scheduler_wd is not None:
            scheduler_wd.deinit()
            scheduler_wd = None
    except Exception:
        pass

    release_sta()
    stop_softap()
    time.sleep_ms(100)

    try:
        from machine import soft_reset

        soft_reset()
    except (ImportError, AttributeError):
        dprint("AP mode: soft_reset unavailable, machine.reset() fallback")
        time.sleep_ms(50)
        reset()


def fibonacci(n, default_sleep_time, max_sleep_time):
    """Calculate the nth Fibonacci number, capped at max_sleep_time."""
    a, b = default_sleep_time, default_sleep_time
    for _ in range(n):
        a, b = b, a + b
        if b >= max_sleep_time:
            return max_sleep_time
    return b


def apply_backoff(default_sleep_time, max_sleep_time):
    """Apply Fibonacci backoff and store state in RTC memory."""
    backoff_counter, _ = retrieve_last_backoff(default_sleep_time)
    backoff_counter += 1
    sleep_time = fibonacci(backoff_counter, default_sleep_time, max_sleep_time)
    rtc_mem.memory(f"{backoff_counter},{sleep_time}".encode())
    return sleep_time


def reset_backoff(default_sleep_time):
    """Reset backoff counter and sleep time."""
    rtc_mem.memory(f"0,{default_sleep_time}".encode())


async def wait_for_connection(retry_interval=1.0, max_attempts=4):
    """Asynchronously wait for WiFi connection with retries.

    If credentials are missing, do not retry. Empty scan still attempts connect
    (radio may not be ready yet); only explicit no_creds aborts early.
    """
    attempts = 0
    try:
        while attempts < max_attempts:
            wdt_feed()
            if await async_do_connect(timeout=10):
                return True
            # no_creds: nothing to try. no_ssid after empty scan is no longer terminal
            # (network_helper falls back to trying configured SSIDs).
            if network_helper.last_connect_status == "no_creds":
                dprint(f"WiFi give up early ({network_helper.last_connect_status})")
                return False
            attempts += 1
            dprint(f"Connection retry {attempts}/{max_attempts}")
            wdt_feed()
            await asyncio.sleep(retry_interval)
        return False
    except Exception:
        dprint("wait_for_connection exception")
        return False


async def disconnect_wifi():
    """Disconnect station Wi-Fi without constructing interfaces unnecessarily."""
    try:
        release_sta()
        stop_softap()
    except OSError as e:
        dprint("disconnect_wifi:", e)
    await asyncio.sleep(0.1)


async def sync_time_if_possible():
    """NTP when online. Boot does this once; upload path re-syncs so RTC does not drift."""
    try:
        ntp_settime()
        dprint("NTP synced", time_iso(time.localtime()))
        return True
    except Exception as e:
        dprint("NTP failed:", e)
        return False


async def prepare_for_deep_sleep(
    np_vcc=None,
    np_obj=None,
    sleep_ms=None,
    face_obj=None,
    tracker=None,
    do_mpu_config=True,
):
    """Centralized preparation for deep sleep.

    - All LED tasks cancelled + inactive (so no background work keeps things alive)
    - LED strip fully blacked out via np_obj
    - DATA pin forced low (prevents back-powering the strip through the data line when VCC gated)
    - np_vcc gate turned off (no current to RGB LEDs)
    - MPU put into known low-power DMP motion detection state (for PIN_WAKE on motion)
    - WiFi fully disconnected
    - Watchdog timer deinitialized

    This is the single place that should perform the power-down sequence so that
    deep sleep current is minimized (target << 1mA when LEDs and MPU are correctly gated).
    """
    dprint("prepare_for_deep_sleep: powering down peripherals for minimal current draw")
    gc.collect()

    # Safe fallbacks to module-level objects
    if np_vcc is None:
        np_vcc = globals().get("np_vcc")
    if np_obj is None:
        np_obj = globals().get("np_obj")
    if sleep_ms is None:
        sleep_ms = DEFAULT_SLEEP_TIME * 1000

    if np_obj:
        try:
            np_obj.fill((0, 0, 0))
            np_obj.write()
        except Exception as e:
            dprint("np_obj blackout warning:", e)
    try:
        Pin(NP_DATA_PIN, Pin.OUT).value(0)
    except Exception as e:
        dprint("DATA pin force-low warning:", e)

    if np_vcc:
        try:
            np_vcc.off()
        except Exception as e:
            dprint("np_vcc.off() warning:", e)

    if do_mpu_config:
        try:
            s = sensor_init(
                enable_mpu=True,
                calibrate=False,
                mean=[0, 0, 0, 0, 0, 0],
                stddev=[1, 1, 1, 1, 1, 1],
                sda_pin=SDA_PIN,
                scl_pin=SCL_PIN,
                intruppt_pin=INTERRUPT_PIN,
            )
            esp32.wake_on_ext0(pin=s._int_pin, level=esp32.WAKEUP_ANY_HIGH)
            if hasattr(s, "configure_for_deep_sleep"):
                s.configure_for_deep_sleep()
            else:
                s.enable_low_power_dmp_motion_detection(threshold=2, sample_rate_div=16)
            dprint("MPU configured for low-power DMP motion detection (deep sleep)")
        except Exception as e:
            dprint("MPU deep-sleep config warning (non-fatal):", e)

    try:
        await disconnect_wifi()
    except Exception as e:
        dprint("disconnect_wifi warning:", e)

    global scheduler_wd
    try:
        if "scheduler_wd" in globals() and scheduler_wd is not None:
            scheduler_wd.deinit()
    except Exception as e:
        dprint("scheduler_wd.deinit() warning:", e)

    dprint(f"→ Deep sleep {sleep_ms // 1000}s")
    deepsleep(sleep_ms)


async def ota_weekly_check(tracker_obj):
    """update/run OTA weekly on"""
    now = time.time()
    last = tracker_obj.running.get("last_ota_check", 0)
    if now - last < tracker_obj.running.get("ota_frequency", DEFAULT_OTA) * 24 * 3600:
        return False
    dprint("Weekly OTA window - checking for firmware update...")
    try:
        scheduler_wd.deinit()
        scheduler_wd.init(period=60000, mode=Timer.PERIODIC, callback=wdt_chk)
        mip.install(tracker_obj.running["ota_address"])
        dprint("OTA successful - rebooting in 1 second...")
        tracker_obj.running["last_ota_check"] = now
        tracker_obj.apply(tracker_obj.running)
        tracker_obj.save()
        await asyncio.sleep(1)
        reset()
    except Exception as e:
        dprint("OTA check failed or no new version:", e)
        tracker_obj.running["last_ota_check"] = now
        tracker_obj.apply(tracker_obj.running)
        tracker_obj.save()
        return False
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

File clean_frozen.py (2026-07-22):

# clean_frozen.py — safe stripping using Python's AST
import ast
import sys
from pathlib import Path


class DocstringStripper(ast.NodeTransformer):
    def visit_Module(self, node):
        if (
            node.body
            and isinstance(node.body[0], ast.Expr)
            and isinstance(node.body[0].value, ast.Constant)
            and isinstance(node.body[0].value.value, str)
        ):
            node.body = node.body[1:]
        return self.generic_visit(node)

    def visit_ClassDef(self, node):
        if (
            node.body
            and isinstance(node.body[0], ast.Expr)
            and isinstance(node.body[0].value, ast.Constant)
            and isinstance(node.body[0].value.value, str)
        ):
            node.body = node.body[1:]
        return self.generic_visit(node)

    def visit_FunctionDef(self, node):
        if (
            node.body
            and isinstance(node.body[0], ast.Expr)
            and isinstance(node.body[0].value, ast.Constant)
            and isinstance(node.body[0].value.value, str)
        ):
            node.body = node.body[1:]
        return self.generic_visit(node)

    def visit_AsyncFunctionDef(self, node):
        return self.visit_FunctionDef(node)


class PrintRemover(ast.NodeTransformer):
    def visit_Expr(self, node):
        if (
            isinstance(node.value, ast.Call)
            and isinstance(node.value.func, ast.Name)
            and node.value.func.id == "print"
        ):
            return None
        return self.generic_visit(node)


def sanitize_empty_bodies(tree):
    """Walk the AST and ensure no compound statement or except handler
    is left with an empty body (which ast.unparse would turn into invalid syntax).
    We deliberately leave orelse/finalbody empty when they become empty:
    ast.unparse will simply omit the now-useless else:/finally: clause.
    """
    for node in ast.walk(tree):
        # main bodies of functions, if, for, while, with, try, classes, etc.
        if hasattr(node, "body") and isinstance(getattr(node, "body", None), list):
            if len(node.body) == 0:
                node.body = [ast.Pass()]
        if isinstance(node, ast.ExceptHandler):
            if len(getattr(node, "body", [])) == 0:
                node.body = [ast.Pass()]
        # Intentionally do NOT populate orelse/finalbody when empty.
        # Empty means "drop this clause" after print/docstring removal.
    return tree


def strip_comments_and_clean(source: str) -> str:
    try:
        tree = ast.parse(source)
    except SyntaxError:
        return source
    tree = DocstringStripper().visit(tree)
    tree = PrintRemover().visit(tree)
    tree = sanitize_empty_bodies(tree)
    ast.fix_missing_locations(tree)
    try:
        import ast as ast_module

        if hasattr(ast_module, "unparse"):
            cleaned = ast.unparse(tree)
        else:
            from astor import to_source

            cleaned = to_source(tree)
    except Exception:
        from astor import to_source

        cleaned = to_source(tree)
    lines = []
    for line in cleaned.splitlines():
        stripped = line.rstrip()
        if stripped.lstrip().startswith("#"):
            continue
        if not stripped:
            continue
        lines.append(line)
    return "\n".join(lines) + "\n"


def clean_file(in_path: Path, out_path: Path):
    source = in_path.read_text(encoding="utf-8")
    cleaned = strip_comments_and_clean(source)
    out_path.write_text(cleaned, encoding="utf-8")


def main():
    if len(sys.argv) != 3:
        sys.exit(1)
    src_dir = Path(sys.argv[1])
    dest_dir = Path(sys.argv[2])
    dest_dir.mkdir(parents=True, exist_ok=True)
    files = [
        "http.py",
        "models.py",
        "mpu6050.py",
        "network_helper.py",
        "rgb.py",
        "util.py",
        "ap_mode.py",
        "ap_session.py",
        "credentials.py",
    ]
    for f in files:
        src = src_dir / f
        if not src.exists():
            continue
        dest = dest_dir / f
        clean_file(src, dest)
    orig_size = sum(
        (src_dir / f).stat().st_size for f in files if (src_dir / f).exists()
    )
    clean_size = sum(p.stat().st_size for p in dest_dir.glob("*.py"))
    saved = orig_size - clean_size
    print(f"Original: {orig_size} B  Cleaned: {clean_size} B  Saved: {saved} B")


if __name__ == "__main__":
    main()

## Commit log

2026-07-16 Initial public commit: FlipBuddy open-source firmware v0.1.0.
    [flipbuddy_con_v0.1.0_led_clip.stl, flipbuddy_con_v0.1.0_led_light_guide.stl, flipbuddy_con_v0.1.0_new_led.FCStd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]
2026-07-21 feat(ap): show device time and battery on captive portal top bar
    Surface RTC datetime plus live ADC percent/voltage (USB-aware) on the
    AP landing page so maintenance mode is more useful offline.
2026-07-21 feat(network): lazy STA and SoftAP radio helpers
    Create WLAN station on first use and add SoftAP bring-up/teardown that
    tolerates OOM so STA and SoftAP can hand off cleanly on ESP32-S3.
2026-07-21 feat(credentials): SoftAP unlock PIN and Wi-Fi NVS profiles
    Factory PIN from device_id, optional custom PIN, and public Wi-Fi profile
    helpers for the captive portal without exposing passwords or device_token.
2026-07-22 feat(ap): SoftAP captive portal with PIN-gated settings
    Status (UTC time, battery, faces, logs), unlock session, Wi-Fi save,
    PIN change, LED test, and ungated device reset for USB-face maintenance.
    [ap_mode.py]
2026-07-22 test: SoftAP host tests, CI pytest, and DIY tooling
    Add pytest coverage for PIN, portal helpers, lazy STA, and handoff marks;
    run tests/ in GitHub Actions; update justfile device lists and package version.
2026-07-31 fix: remap face names to match physical LED pinout
    Rename NeoPixel face labels and cube_face_upward gravity returns so
    detection lines up with the enclosure (back→front, left→bottom,
    front→back, bottom→left, right→top, top→right). Cutout orientation
    names are unchanged.
    [mpu6050.py, rgb.py]
2026-07-31 docs: v0.1.2 release notes, changelog, and version pointers
    Document the face pinout/gravity remap, upgrade path from 0.1.1
    (full reflash), checksum, and bump README / pyproject / CONTRIBUTING
    examples to esp32_s3_flipbuddy_0.1.2.bin.
2026-07-31 fix(rgb): correct front/back cutout triad LED faces
    Swap triad mappings so front_cutout lights bottom/left/back and
    back_cutout lights top/right/front after the face pinout remap.
    [rgb.py]
2026-07-31 docs: ship v0.1.3 release notes (cutout triad fix)
    Document the 0.1.3 frozen image (triad LED correction on top of
    0.1.2 face remap), bump version pointers, and mark 0.1.2 cutout
    triads as superseded for new flashes.
2026-08-07 docs: clarify FlipBuddy as face-up time tracking, not an alarm
    Expand day-to-day section for bidirectional app sync, device
    settings, and offline defaults with the last known face map.
2026-08-08 refactor: use const() for defaults, add FSM state constants, improve session durability and NVS hygiene
    - enlarge NVS blob buffer, strip ephemeral upload keys before save
    - finalize open sessions on SoftAP hand-off and stop-face
    - reconcile open sessions after NTP / power-loss instead of dropping them
    - preserve tracking_log on hash mismatch instead of factory reset
    - pass battery capacity to voltage reads, add tracking_log_nonempty helper
    [http.py, main.py, models.py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]
2026-08-29 feat(wifi): last-AP fast reconnect and fail-fast STA
    Remember the last successful home AP in NVS and skip the extra scan
    on the next join. Missing AP or wrong password fail in hundreds of
    milliseconds instead of burning a long retry loop.
2026-08-29 feat(ap): WPA2-PSK SoftAP, keep HTTP portal
    Join password is FB plus the last 6 alphanumeric of device_id.
    password and authmode go in one config() call. Captive portal stays
    http://10.20.30.40/. SECURITY.md no longer describes an open AP.
2026-08-29 feat(fsm): MPU live face preview after wake
    After the 7 s assigned-face map, sample the MPU at 5 Hz and light the
    live assigned face. Commit tracking after ~10 s still, or skip after
    40 s. Timer wakes still take one sample.
2026-08-29 docs: LED settle/SoftAP behaviour and 0.1.5 notes
    Document the 7 s assigned-face map, live preview, 10 s settle, and
    yellow USB-face SoftAP LEDs. Bump the tree to 0.1.5 / MicroPython 1.28.
2026-08-29 fix(fsm): 10s MPU settle and tracking blink after preview
    Reuse the MPU after settle (no second I2C init), stop the gyro IRQ
    during sampling, and sleep only the remainder of each 5 Hz slot so
    still-hold is ~10 s not ~20 s. Drop the solid preview LED before
    starting the tracking blink.
2026-08-29 fix(fsm): 10s still-hold and PIN_WAKE tracking blink
    Settle is wall-clock 10 s after landing on a face, then the usual
    tracking blink (active() clears _stop after the map). Changelog and
    v0.1.5 release notes included.
2026-08-29 docs: fix README links and pickup LED wording
    Correct fast-track and assembly anchors. Describe 10 s still-hold then
    tracking blink. Note last-AP reconnect, MicroPython 1.28, and the 0.1.5
    flash default.
2026-09-01 feat(pairing): SoftAP claim; house Wi-Fi stays in NVS
    Unclaimed cubes serve a pairing portal after just gen-ap-psk.
    Host PSK is ap_psk.json; fast-track / diy upload main.py and that
    file, not credentials.json. Optional https API base; hard-reset
    when done. Portal matches dashboard XXXX-XXXX codes.
    Claim POST never sends house SSID/password (optional cube ap_psk
    only). House Wi-Fi is NVS-only; recovery JSON is identity and is
    stripped of wifi before it reaches the cube.
2026-09-01 docs: pair with host SoftAP password; JSON recovery is identity only
    Fast track and DIY do not upload dashboard JSON. Join FlipBuddy-XXXX
    with the host PSK and type the pairing code. put-credentials restores
    device_id / device_token; house Wi-Fi in that file is ignored.
2026-09-01 feat: v0.2.0 claim pairing and dual-OTA Super Mini freeze
    BREAKING CHANGE: v0.1.0-v0.1.5 frozen images and JSON-first pairing do
    not work with Production claim pairing or dual-OTA. USB-flash
    esp32_s3_flipbuddy_0.2.0-ota.bin. GitHub Releases ship USB images only
    (factory + *-ota.bin). App-slot OTA stays on flipbuddy.app.
2026-09-01 docs: assembly guide for firmware 0.2.0 claim pairing
    Replace the v0.1.x PDF with the 0.2.0 export: Super Mini frozen OTA
    flash, just fast-track, and cube Wi-Fi Add Device pairing.
2026-09-02 feat(pairing): all six LEDs yellow during unclaimed SoftAP
    Light every LED solid yellow while the pairing portal is up; claimed
    USB-face SoftAP still uses the yellow triad. Document the behaviour,
    add tests, and refresh 0.2.0 USB image checksums.
2026-09-02 feat(hw): LittleFS settings overlay for Super Mini pins
    Move Super Mini GPIO and product tunables into settings.py on the
    filesystem so frozen images can change pins without a rebuild. Unclaimed
    pairing brings the LED rail up once in the portal; claimed boot does it
    before constructing the NeoPixel strip.
2026-09-02 chore: v0.2.1 Super Mini settings overlay
    LittleFS settings.py is the pin and product overlay. Public comments and
    tests stay Super Mini only. Fast-track copies main.py, settings.py, and
    the host SoftAP password.
2026-09-03 fix(boot): faster PIN_WAKE LED bring-up
    Lazy-import pairing on claimed wake, raise the LED rail before Config,
    and keep rgb.pinout local so frozen rgb does not alias LittleFS settings.
    Refresh v0.2.1 USB image checksums.
2026-09-04 feat(pairing): motion-only deep sleep after unclaimed portal ends
    Leave the SoftAP after timeout or failure instead of retrying forever.
    Wake only on MPU INT (no RTC timer) so an unclaimed cube stays asleep
    until it is picked up.
2026-09-04 feat(fsm): skip tracking when settings.active is false
    Store the remote active flag, blink red on the upward face (triad on
    cutouts), finalize any open session, and sleep on the upload interval.
    Motion wakes skip Wi-Fi; timer, USB, and a pending log still check config.
2026-09-04 feat(http): reuse one TLS socket per wake with HTTP/1.1 keep-alive
    HttpSession serializes GET/POST on a single connection. Preview posts
    are fire-and-forget with a short timeout and do not open a new socket.
    OTA still uses the close-after-use GET helper for large bodies.
2026-09-04 feat(fsm): warm radio during the map and post live face previews
    Persist live_ok_until in NVS (epoch only, outside Config hash). Pickup
    wakes join Wi-Fi during the 7s assigned-face map when that hint is
    fresh and tracking is on. Face changes POST sensor/live_event without
    connecting. Tracking-off still skips the radio. Dim the strip during TX.
2026-09-04 chore: v0.2.2 version pin and release notes
    Pin FIRMWARE_VERSION, host flash defaults, and README to 0.2.2.
    Document pause tracking, unclaimed motion sleep, and live dashboard
    preview. USB image checksums wait for the freeze.
2026-09-05 docs(fsm): sync fsm.dot with SoftAP gate, settle, and tracking-off
    Bring the power/state diagram and comments in line with current Boot,
    Active, and Upload FSM behavior (early SoftAP handoff, FACE_SETTLE,
    TRACKING_OFF, offline-first boot, pairing identify).
2026-10-22 fix: name the LiPo as 600 mAh
    The README estimate, the FSM note, and the voltage helper default now use 600 mAh.
2026-10-30 feat: pause check-back and per-chip OTA gate
    Tracking-off sleep uses 5 min, 30 min, or 2 h when that interval is set,
    otherwise the upload interval. A pickup does not restart the deadline or
    join Wi-Fi.
    An app image for another chip is refused before the slot is written. A
    download that cannot select a slot does not record the version as applied.
    Frozen boot.py confirms the running slot and does not replace main.py.

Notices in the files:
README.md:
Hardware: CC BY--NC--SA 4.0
